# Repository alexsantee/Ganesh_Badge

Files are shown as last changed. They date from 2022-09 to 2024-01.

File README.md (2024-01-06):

# Ganesh Badge

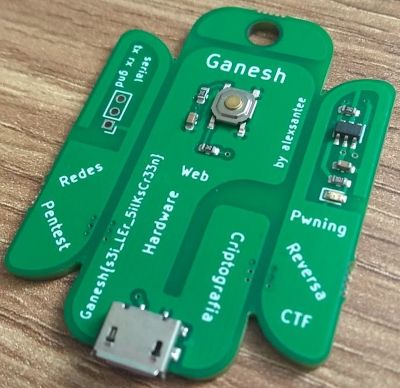
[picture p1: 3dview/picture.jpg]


The board is entirely based on [Ganesh](https://ganesh.icmc.usp.br/)'s logo, the back side has the logo printed in silkscreen and the front side has a circuit part shaped like the logo, which serves as a ground plane. The front also has the names of our main study areas.

The project is based in the PIC10F200 microcontroler, which offers low cost, decent current sourcing and 4 I/O pins.
The PCB features an LED, header pins intended as a serial and a programming interfaces and a button. These are for creating simple CTF-like challenges yielding a flag, being the button a mean of switching which challenges are currently running.
The lower part of the board has an USB micro-B connector for powering and the top part has a hole intended for easy carrying as a keychain, necklace or even nailing it to a wall.

Mouse bites from [this](https://github.com/madworm/Panelization.pretty) repository.

The PCB was made in KiCAD and intended for low-cost manufacturing at JLCPCB

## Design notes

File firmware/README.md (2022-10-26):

# Firmware

The firware is made for the PIC10F200 series and was compiled with MPASM assembler at MPLAB v5.35 IDE (later versions deprecated MPASM).

The code basicaly outputs flags through the TX pin and the LED. It reacts to the button press and the RX pin revealing new flags.

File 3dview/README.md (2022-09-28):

# 3dview

This section is a version of the badge using footprints with 3d models available. It's just for displaying and not for actual manufacturing.

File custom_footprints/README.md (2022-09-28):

# custom_footprints

The MicroQTJ and TS-1187A-B-A-B, are footprints for the USB Micro-B port and the button, which were not available by default at KiCAD.
MicroQTJ_2pads and SOT-23-6_narrow, are modified versions of the USB and MCU footprints to let the pads farther apart and reduce the chance of manufacturing errors.

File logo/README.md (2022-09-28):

# logo

Contains footprints for different sizes of the logo

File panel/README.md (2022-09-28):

# panel

This is a the panelized board with 4 badges in one board for lower cost manufacturing. It is intended to be detached through the mouse bites

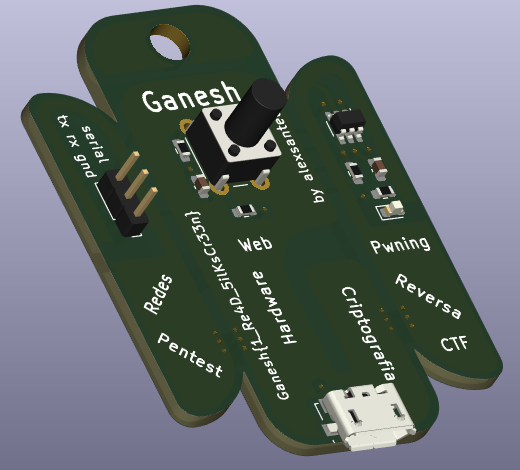
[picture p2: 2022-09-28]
3dview/3dview.png

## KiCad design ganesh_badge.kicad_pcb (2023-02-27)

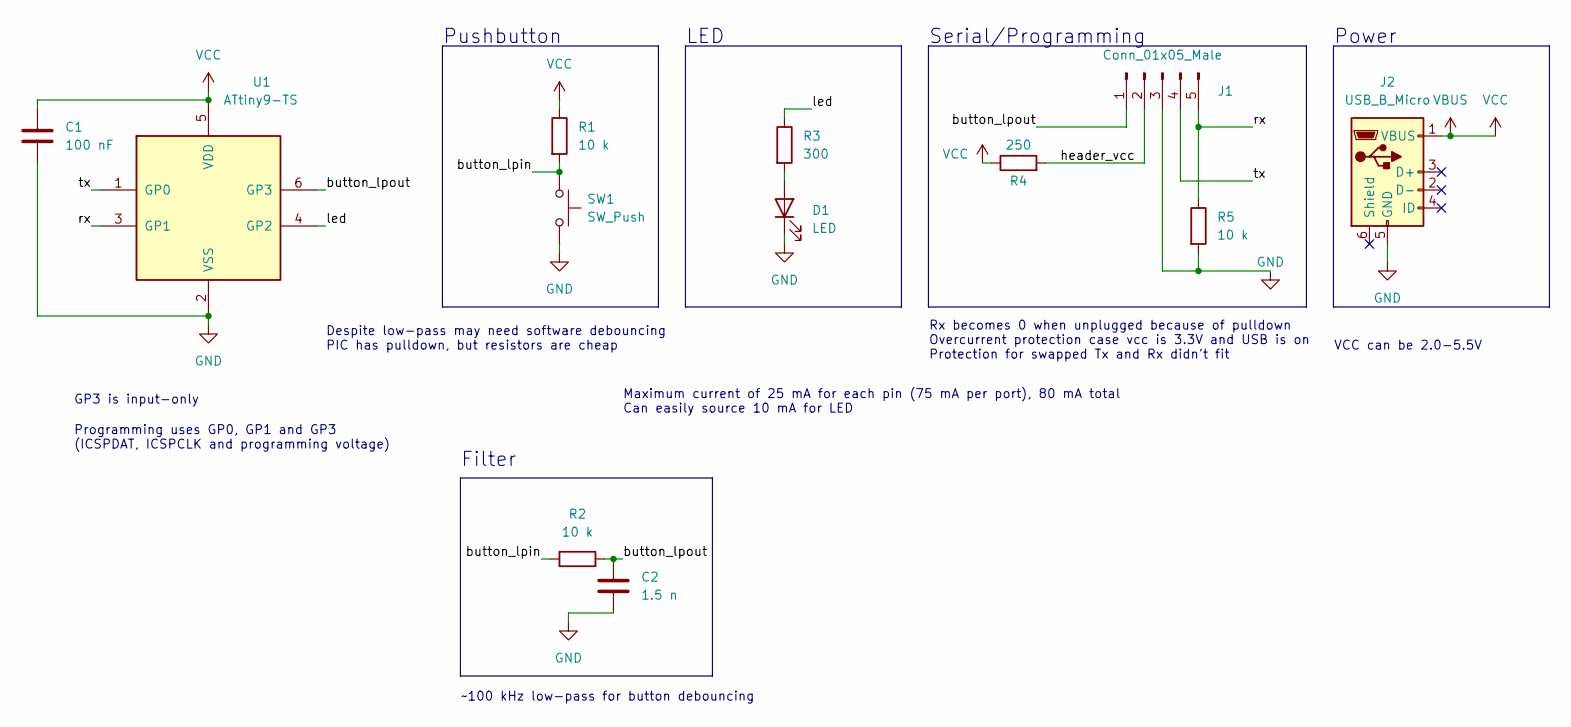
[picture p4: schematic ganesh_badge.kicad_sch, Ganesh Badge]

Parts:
C1: 100 nF; C_0603_1608Metric
C2: 1.5 n; C_0603_1608Metric
D1: LED; LED_0603_1608Metric
J1: Conn_01x05_Male; PinHeader_1x05_P2.54mm_Vertical
J2: USB_B_Micro; MicroQTJ_2pads
R1, R2, R5: 10 k; R_0603_1608Metric
R3: 300; R_0603_1608Metric
R4: 250; R_0603_1608Metric
SW1: SW_Push; TS-1187A-B-A-B
U1: ATtiny9-TS; SOT-23-6_narrow

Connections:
/button_lpin: R1.2, R2.1, SW1.1
/button_lpout: C2.1, J1.1, R2.2, U1.6 (GP3)
/header_vcc: J1.2, R4.2
/led: R3.1, U1.4 (GP2)
/rx: J1.5, R5.1, U1.3 (GP1)
/tx: J1.4, U1.1 (GP0)
GND: C1.2, C2.2, D1.1 (K), J1.3, J2.5 (GND), R5.2, SW1.2, U1.2 (VSS)
unnamed: D1.2 (A), R3.2
VBUS: C1.1, J2.1 (VBUS), R1.1, R4.1, U1.5 (VDD)

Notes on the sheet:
Despite low-pass may need software debouncing PIC has pulldown, but resistors are cheap
Maximum current of 25 mA for each pin (75 mA per port), 80 mA total Can easily source 10 mA for LED
Filter
~100 kHz low-pass for button debouncing
Programming uses GP0, GP1 and GP3 (ICSPDAT, ICSPCLK and programming voltage)
Rx becomes 0 when unplugged because of pulldown Overcurrent protection case vcc is 3.3V and USB is on Protection for swapped Tx and Rx didn't fit
Serial/Programming
VCC can be 2.0-5.5V
Pushbutton
Power
LED
GP3 is input-only

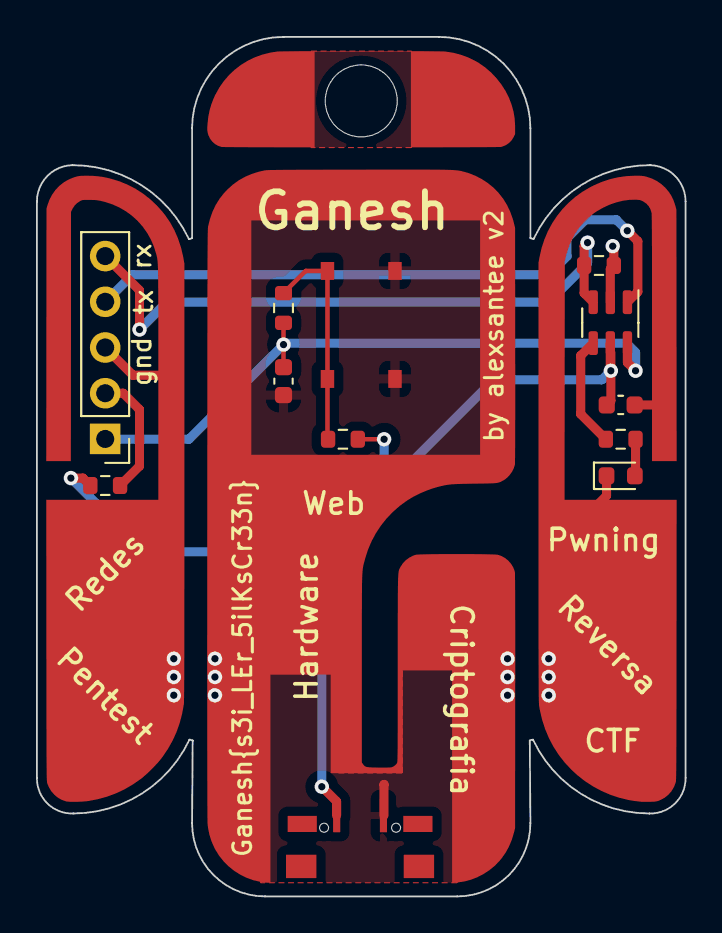
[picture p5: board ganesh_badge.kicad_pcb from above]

Board: 2 copper layers, 36.0 x 47.8 mm, 15 parts (1 on the bottom side), 9 nets.

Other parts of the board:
Hole: MountingHole_4mm
Logo_silk: LOGO; 35x46_2
logo_cobre: LOGO; 35x46_2-furado

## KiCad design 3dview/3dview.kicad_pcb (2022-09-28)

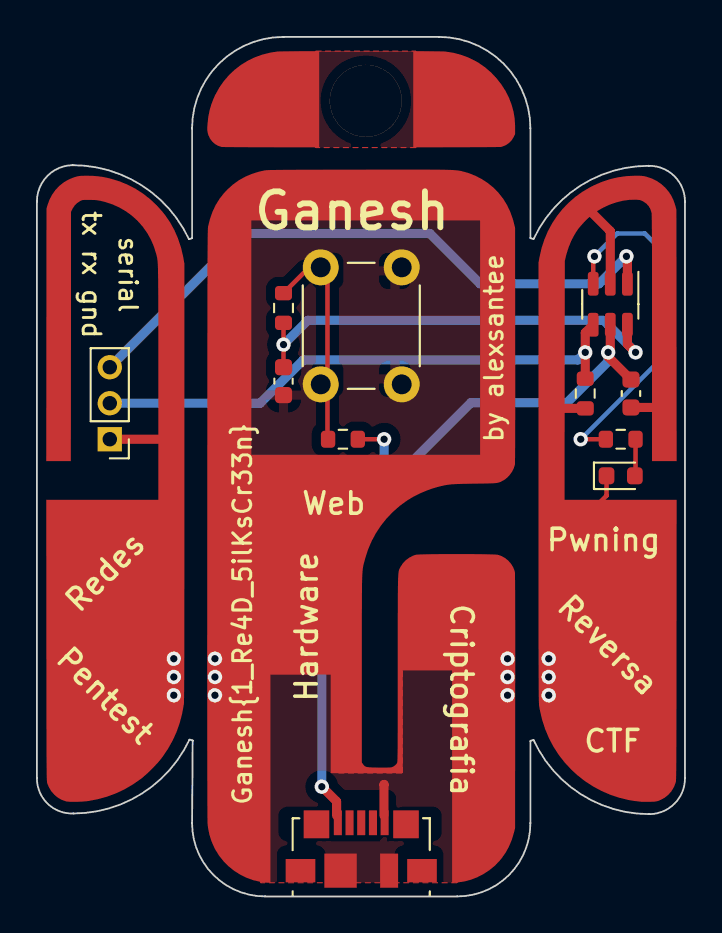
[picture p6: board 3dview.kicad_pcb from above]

Board: 2 copper layers, 36.0 x 47.8 mm, 14 parts (1 on the bottom side), 8 nets.

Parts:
C1: 100 nF; C_0603_1608Metric
C2: 1.5 n; C_0603_1608Metric
D1: LED; LED_0603_1608Metric
Hole: MountingHole_4mm
J1: Conn_01x03_Male; PinHeader_1x03_P2.00mm_Vertical
J2: USB_B_Micro; USB_Micro-B_Molex_47346-0001
Logo_silk: LOGO; 35x46_2
R1, R2, R4: 10 k; R_0603_1608Metric
R3: 300; R_0603_1608Metric
SW1: SW_Push; SW_PUSH_6mm_H9.5mm
U1: ATtiny9-TS; SOT-23-6
logo_cobre: LOGO; 35x46_2-furado

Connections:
/button: R2.2, R4.1, SW1.1
/button_lp: C2.1, R4.2, U1.6 (~RESET/PB3)
/led: R3.1, U1.3 (PB1)
/rx: J1.2, R1.1, U1.4 (PB2)
/tx: J1.3, U1.1 (PB0)
GND: C1.2, C2.2, D1.1 (K), J1.1, J2.5 (GND), R1.2, SW1.2, U1.2 (GND)
unnamed: D1.2 (A), R3.2
VBUS: C1.1, J2.1 (VBUS), R2.1, U1.5 (VCC)

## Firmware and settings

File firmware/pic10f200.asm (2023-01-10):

; Notes:
    
; Call instruction dest are 8 bit only, subroutines must be at first 256 addr
; Hardware stack depth is two (be careful!!!)

; Instruction time is four clock cycles of 4 MHz, so instrucion time is 1us
; Timer counts instruction clock (1MHz)
; For 9600 baud rate, bit time is 104,1 us (should I transmit faster?)
; I think 0.5s is a good period to blink the LED
; but even with the prescaler its bigger than 8-bit TMR0 can handle

; General purpose registers are from 10h-1fh (16 registers) or 8h-1fh at f202
    
#include "p10f200.inc"

; CONFIG
; __config 0xFEB
 __CONFIG _WDTE_OFF & _CP_OFF & _MCLRE_OFF; disable whatchdog and set GP3 as IO
MAIN_PROG CODE                      ; let linker place main program
 
RES_VECT  CODE    0x0000            ; processor reset vector
    GOTO    START                   ; go to beginning of program

UART_FLAG_1
 movfw UART_IDX
 addwf PCL, F
 retlw 'G'
 retlw '{'
 retlw 'U'
 retlw 'A'
 retlw 'R'
 retlw 'T'
 retlw '1'
 retlw '}'

UART_FLAG_2
 movfw UART_IDX
 addwf PCL, F
 retlw 'G'
 retlw '{'
 retlw 'U'
 retlw 'A'
 retlw 'R'
 retlw 'T'
 retlw '2'
 retlw '}'
 
UART_FLAG_3
 movfw UART_IDX
 addwf PCL, F
 retlw 'G'
 retlw '{'
 retlw 'U'
 retlw 'A'
 retlw 'R'
 retlw 'T'
 retlw '3'
 retlw '}'
 
LED_FLAG_1
 movfw LED_IDX
 addwf PCL, F
 retlw 'G'
 retlw '{'
 retlw 'L'
 retlw 'E'
 retlw 'D'
 retlw '1'
 retlw '}' 

LED_FLAG_2
 movfw LED_IDX
 addwf PCL, F
 retlw 'G'
 retlw '{'
 retlw 'L'
 retlw 'E'
 retlw 'D'
 retlw '2'
 retlw '}' 

LED_FLAG_3
 movfw LED_IDX
 addwf PCL, F
 retlw 'G'
 retlw '{'
 retlw 'L'
 retlw 'E'
 retlw 'D'
 retlw '3'
 retlw '}' 
 
RX_FLAG
 addwf PCL, F
 retlw 'G'
 retlw '{'
 retlw 'R'
 retlw 'X'
 retlw '}' 
 
; No part of the program reaches this region
; This flag is intended to be obtained through a flash dump
UNREACHABLE_FLAG
 addwf PCL, F
 retlw 'G'
 retlw '{'
 retlw 'R'
 retlw 'O'
 retlw 'M'
 retlw 'D'
 retlw 'u'
 retlw 'm'
 retlw 'p'
 retlw '}' 

; This flag is just a comment, for people who found the repository
; G{Spying_G1tHub}
 
; Registers:
TMR0 EQU 01h
PCL EQU 02h; Program Counter low bits
 
STATUS EQU 03h
CARRY EQU 0; Carry is status bit 0
ZERO  EQU 2; Zero is status bit 2
  
GPIO EQU 06h
TX  EQU 0
LED EQU 2

; Constants
LEVEL_NUM EQU d'3'
; UART timings obtained via simulation
START_BIT_TIME EQU d'31'
DATA_BIT_TIME  EQU d'31'
END_BIT_TIME   EQU d'26'
; LED blinking counter, obtained via simulation to ~0.5s
LED_TIME       EQU d'209'
 
; Variables:
PRINT_BUF EQU 10h
UART_TIME_COUNTER EQU 11h
UART_IDX EQU 12h
UART_BIT EQU 13h

LED_TIME_COUNTER EQU 14h
LED_IDX EQU 15h
LED_BIT EQU 16h

FLAGS EQU 17h
BUTTON_F    EQU 0; BUTTON is bit 0 of flags
RX_LAST_F   EQU 1; Last RX state is bit 1 of flags
RX_CHANGE_F EQU 2; RX change is bit 2 of flags

LEVEL EQU 18h
 
; Functions
 
; Flag selection functions (use call)
UART_FLAG_SELECT
 movfw LEVEL
 addwf PCL, F
 GOTO UART_FLAG_1
 GOTO UART_FLAG_2
 GOTO UART_FLAG_3
 
LED_FLAG_SELECT
 movfw LEVEL
 addwf PCL, F
 GOTO LED_FLAG_1
 GOTO LED_FLAG_2
 GOTO LED_FLAG_3
 
; Sends byte from PRINT_BUF through UART interface
UART_SEND
 
 ; sets line from high to low for start bit
 bcf GPIO, TX
 
 ; wait 104 us (9600 baud rate time)
 movlw START_BIT_TIME
 movwf UART_TIME_COUNTER
 decfsz UART_TIME_COUNTER, F
 GOTO $-1
 
 ; sends the data through TX
 GOTO PRINT_W
PRINT_W_RET
 
 ; sets line from low to high for end bit
 bsf GPIO, TX
 
 ; wait 104 us (9600 baud rate time)
 movlw END_BIT_TIME
 movwf UART_TIME_COUNTER
 decfsz UART_TIME_COUNTER, F
 GOTO $-1
 
 retlw 0

 ; Sends byte through serial interface from PRINT_BUF, part of UART_SEND
PRINT_W
 ; starts from byte 0 for shifting UART_BIT (UART is little endian!)
 movlw 01h
 movwf UART_BIT
 
PRINT_LOOP
  ; clears carry
  bcf STATUS, CARRY
  ; selects bit
  movfw UART_BIT
  andwf PRINT_BUF, W ; may set ZERO flag
  
  ; sends to GPIO
  btfsc STATUS, ZERO; skips if selected bit was a 1
  bcf GPIO, TX; sets TX to 0
  btfss STATUS, ZERO; skips if selected bit was a 0
  bsf GPIO, TX; sets TX to 1
  
  ; wait 104-11 us (9600 baud rate time - instructions time)
  movlw DATA_BIT_TIME
  movwf UART_TIME_COUNTER
  decfsz UART_TIME_COUNTER, F
  GOTO $-1
  
  ; increments bit
  rlf UART_BIT, F
  btfss STATUS, CARRY
  GOTO PRINT_LOOP
  
 goto PRINT_W_RET
 
START
 ; clear memory (8h-1fh at f202 and 10h-1fh at f200)
 clrf 8h
 clrf 9h
 clrf 0ah
 clrf 0bh
 clrf 0ch
 clrf 0dh
 clrf 0eh
 clrf 0fh
 clrf 10h
 clrf 11h
 clrf 12h
 clrf 13h
 clrf 14h
 clrf 15h
 clrf 16h
 clrf 17h
 clrf 18h
 clrf 19h
 clrf 1ah
 clrf 1bh
 clrf 1ch
 clrf 1dh
 clrf 1eh
 clrf 1fh
 ; OSSCAL register (calibration) is erased when flash is erased
 
 ; Starts with LED and TX high
 movlw b'11111111'
 movwf GPIO
 ; TRIS = 0b 1111 1010; Set GP0 and GP2 (tx and led) as outputs
 movlw b'11111010'
 tris 6
 ; OPTION = 0b 1101 0100 ; Set timer to internal clock, prescaler is 1:32
 ; bits are:
 ; 7   - *GPWU (wake up on change)
 ; 6   - *GPPU (internal pull ups)
 ; 5   - T0CS (timer source 1=IO pin, 0=internal oscilator)
 ; 4   - T0SE (edge select 1=fall 0=rise)
 ; 3   - PSA (prescaler assignment 1=watchdog 0=timer0)
 ; 2-0 - prescaler rate
 movlw b'11010100'
 option
 
 ; LED initialization
 bsf LED_BIT, 7; starts at MSB for big endianess
 
 ; For each main loop the MCU:
 ; 1. Updates LED state
 ; 2. Sends Message through TX
 ; 3. Keeps checking for button press, RX and timer
 ; 4. Reacts to button press or RX
 
MAIN_LOOP
 ; 1. Updates LED state
 
 ; gets current bit
 call LED_FLAG_SELECT
 andwf LED_BIT, W
 
 ; sends to GPIO
 btfsc STATUS, ZERO; skips if selected bit was a 1
 bcf GPIO, LED; sets LED to off
 btfss STATUS, ZERO; skips if selected bit was a 0
 bsf GPIO, LED; sets LED to on
 
 ; shifts bit position
 bcf STATUS, CARRY
 rrf LED_BIT, F
 btfss STATUS, CARRY
 goto END_LED
 ; if was the last bit, resets bit and increments char position
 bsf LED_BIT, 7
 ; if at an '}' resets index, else incremets it
 call LED_FLAG_SELECT
 xorlw '}'
 btfss STATUS, ZERO
 goto INCR_LED_IDX
RESET_LED_IDX
 clrf LED_IDX
 goto END_LED
INCR_LED_IDX
 incf LED_IDX, f
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

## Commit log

2022-09-28 first design
    [100x100.kicad_pcb, 3dview.kicad_pcb, ganesh_badge.kicad_pcb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]
2022-10-17 created PIC10 version
    [ganesh_badge.kicad_pcb, ganesh_badge.kicad_sch]
2023-01-10 simple text fixes
    [ganesh_badge.kicad_pcb, ganesh_badge.kicad_sch]
2023-01-10 Clears memory for real device
2023-01-10 panelization fixes
    [100x100.kicad_pcb, 100x100_old.kicad_pcb]
2023-01-10 changed 3d view to picture of actual board
2023-02-22 changes pic_version to main version and discards attiny
    [ganesh_badge.kicad_pcb, ganesh_badge.kicad_sch]
2023-02-22 changed header to be more compatible with pickit3
    [ganesh_badge.kicad_pcb, ganesh_badge.kicad_sch]
2023-02-27 added ground plane to back layer for aesthetics and better EMI
    [ganesh_badge.kicad_pcb]
